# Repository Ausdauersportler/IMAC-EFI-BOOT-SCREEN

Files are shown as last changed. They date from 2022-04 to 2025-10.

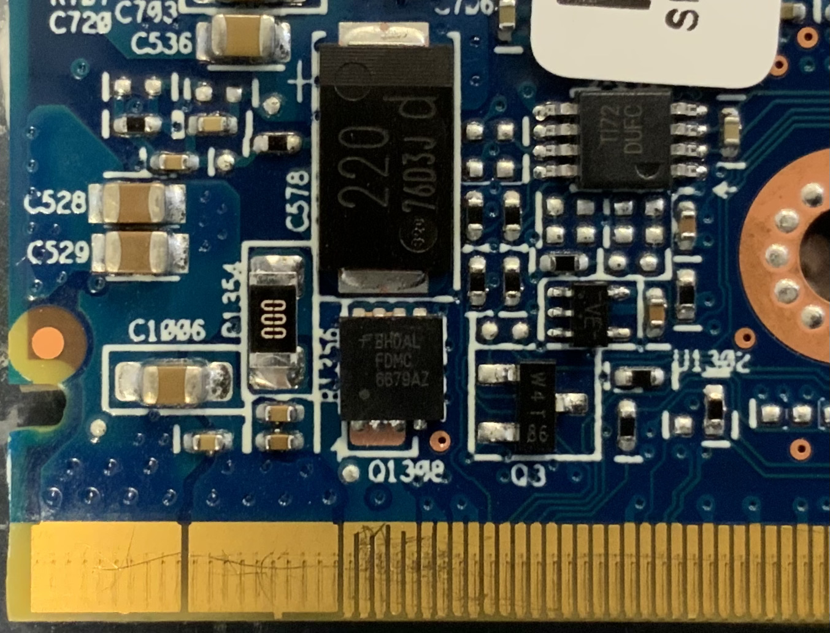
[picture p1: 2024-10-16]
images/modded_corner.jpg

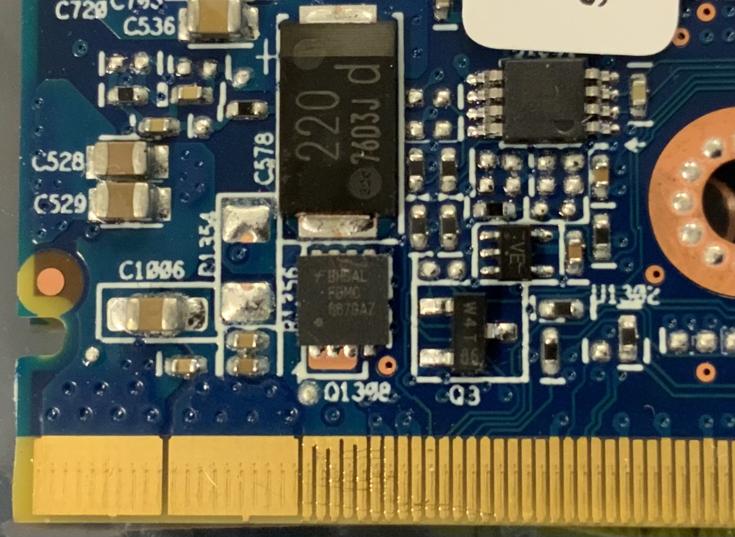
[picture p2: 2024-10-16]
images/unmodded_corner.jpg

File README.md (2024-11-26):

# IMAC-EFI-BOOT-SCREEN

How to create an EFI boot screen vBIOS for Apple 2009 to Mid 2011 iMac systems using AMD MXM3 graphics cards

My goal is to provide a comprehensive guide how to construct EFI BIOS versions for some AMD MXM cards. As described in detail in this [thread](https://forums.macrumors.com/threads/2011-imac-graphics-card-upgrade.1596614/post-17425857) owners of modular Apple iMac models built in 2009-2011 with MXM slot graphcs card can replace the original ATI card either with an Nvidia Kepler or an AMD GCN 1.0 to 4.0 card. While there has been a lot of success offering an EFI boot screen with NVIDIA cards development stuck with the AMD cards at some point where an iMac firmware modification has been proposed. Although the firmware modification is quite simple the adoption rate is frankly speaking zero. IMHO this is still the best way to go. Nevertheless even this method will need a BIOS constructed in the same way as described here within the wiki. 

Just to complete this introduction: 
Lately [improvements](https://forums.macrumors.com/threads/imac-2011-maxwell-and-pascal-gpu-upgrade.2300989/post-30017630) have been made to add a NVIDIA Maxwell and Pascal card, but please note there are no macOS drivers available within any macOS versions starting with Mojave, and there is limited EFI boot screen support.

The [wiki](https://github.com/Ausdauersportler/IMAC-EFI-BOOT-SCREEN/wiki) decribes tools, sources, methods, orignal limitations, solutions and state of the current development.  

## iMac models supported

This repository is limited to these eight iMac models published from 2009 to 2011:

- iMac9,1 Early 2009 A1225 24 inch (LVDS) (using a modified EnableGop9,1 driver, see note 1)
- iMac10,1 Late 2009 A1311 21.5 inch (LVDS) (see note 2)

- iMac10,1 Late 2009 A1312 27 inch (eDP, see note 3 about EG2)

- iMac11,1 Late 2009 A1312 27 inch (eDP)
- iMac11,2 Mid 2010 A1311 21.5 inch (eDP)
- iMac11,3 Mid 2010 A1312 27 inch (eDP)

- iMac12,1 Mid 2011 A1311 21.5 inch (eDP)
- iMac12,2 Mid 2011 A1312 27 inch (eDP)

Notes: 

1. Finally it was possible to include the iMac9,1 Mid 2009 A1225 24 inch to this list. The [2.93 GHz](https://everymac.com/systems/apple/imac/specs/imac-core-2-duo-3.06-24-inch-aluminum-early-2009-specs.html) and [3.06 GHz](https://everymac.com/systems/apple/imac/specs/imac-core-2-duo-2.93-24-inch-aluminum-early-2009-specs.html) versions were equipped with MXM3 slots and non metal graphics cards (GT120, GT130, AMD 4850). Best cards to use are the AMD FirePro M4000, M5100, W5170M, and M6000. The power hungry Saturn cards M6100 and W6170M/W6150M will over heat the system under load rapidly. This system needs a special EnableGop91 driver. All vBIOS files are marked aka named like this and include the LVDS string, too. Some more recent NVIDIA MXM3 cards may still have LVDS signaling support and therfore may work with these iMac9,1 system, too (never tested).

2. vBIOS file names contain the string LVDS, but not show the EnableGop91 string (see note 1). Unfortunately all more recent AMD GPUS starting the the Polaris/GCN4 architecture lack LVDS signaling hardware support. Therefore you cannot get those cards to display the boot screen unless you connect the internal display using a third party display driver board the external DP port - making it an externally connected display.

3. EG2 versions of vBIOS do not run on iMac10,1 A1312 systems, you get only a white screen in power on/boot. EG versions support all types of Macs listed.

4. Althout one cannot modify the legacy part of the vBIOS it is possible to inject a modified legacy vBIOS (the first 64K of it) using an SSDT or OpenCore DeviceProperties (ATY,bin_image) to enable the backlight control on Big Sur and Monterey. This mod does not apply or work with any Windows installation. Adding the EnableGop driver brought back EFI boot screen support. First and only replacement card which enables both external display connectors on iMac12,2.

5. Same method as described above enables virtual brightness control on RX6600M. Although values in ioreg and NVRAM are changed the brightness of the display itself does not change, probably because MXM PINS 23,25,27 are not connected as described in this [video](https://www.bilibili.com/video/BV1Ec411d7z6). Additionally the GOP driver has to be patched with the [Syncretic tool](https://forums.macrumors.com/threads/amd-radeon-rx-6800-xt-6900-xt-for-macos.2262295/page-36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). Unfortunately neither EnableGop not OpenCore are able to switch on the internal backlight, so the display comes to life late at the login screen. 

## AMD graphcis cards supported

Currently we have tested these cards and can confirm the method works with:

- AMD FirePro M4000
- AMD FirePro M5100
- AMD FirePro M6000
- AMD FirePro W5170M

- AMD FirePro M6100
- AMD FirePro W6150M
- AMD FirePro W6170M

- AMD FirePro W7170M 
- AMD FirePro S7100X

- AMD Radeon Pro WX4130 mobile
- AMD Radeon Pro WX4150 mobile
- AMD Radeon Pro WX4170 mobile

- AMD Radeon Pro WX3200 mobile

- AMD Radeon Pro RX470 mobile
- AMD Radeon Pro RX480 mobile
- AMD Radeon Pro WX7100 mobile

- AMD Radeon Pro RX5500XT mobile (see note 4 above)
- AMD Radeon Pro RX6600M mobile (see note 5 above)

## Hardware upgrade (wiki)

You will find an [overwiew](https://github.com/Ausdauersportler/IMAC-EFI-BOOT-SCREEN/wiki/WWWW) which card works in which iMac and how to start the upgrade project and some more hardware related information about minor soldering tasks needed for a few cards to make them fully compatible in a newly added hardware section.

## Credits

Most knowledge has been gathered by me from contributions made by [Nick [D]vB](https://github.com/iMacGFX), [nikey22](https://github.com/nikey22), and [internetzel](https://github.com/internetzel) who spent some nights to explain everything in detail to me and who has much more patience to dive deeply into this matter than I do. Hope he will join me to fill this repository with contents. Last but not least thanks to [dfranetic](https://github.com/franetic), he finished what I could not have done. Great team!

Thanks to [rthpjm](https://forums.macrumors.com/members/rthpjm.535915/) for finding a W6150M and the necessary legacy vBIOS in some HP firmware update. Special thanks to [edwardgeo](https://forums.macrumors.com/members/edwardgeo.1274066/) for countless ideas and incredible knowledge about indepth AMD vBIOS modifications. All the best if these dark times!

[m0bil](https://github.com/m0bil) has become the expert for all NVIDIA modifications and probably he should start a similar repository about it and more importantly to this project he is the undisputed master of all iMac firmware modifications.

Finally many thanks to [Mike Beaton](https://github.com/mikebeaton) who developed an EFI driver named [EnableGop](https://github.com/mikebeaton/OpenCorePkg/tree/master/Staging/EnableGop) usable for both MacPro5,1 and modular iMacs as listed above using either Nvidia or AMD graphics cards to enable the EFI boot picker. I had to modify this driver a little bit to make it work on the older (LVDS) iMac9,1 model. This change has not been included into the EnableGop source tree and you need to get the driver named EnableGop91 compiled from this page. It works as desigend, with AMD and likely with NVIDIA cards as well.

## Support

If you want to support the AMD (i)Mac vBIOS development or just buy me a coffee [donations](https://www.paypal.com/paypalme/Ausdauersportler) are greatly appreciated.

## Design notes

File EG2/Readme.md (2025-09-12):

EFI compatible vBIOS versions based on Apples own EG2 driver (extracted from different MacBookPro and iMac firmware).
Most native experience when using these EG2 versions, no glitches and no display sync problems. 
Needs an iMac firmware modification as described in the wiki. 
An alternative solution is deleting the VGA driver from the legacy part to gain some space needed to add both the CoreEG2 and EDIDParser modules.

Optimal choice for macOS only systems.

UEFI Windows support only with AMD GOP injection via OCLP.

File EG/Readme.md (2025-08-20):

All vBIOS versions uploaded here are created to use in Apple iMac models, only. No support for any PC laptops here.

Tried to use speaking file names to avoid confusion after downloading multiple files from this and other folders in this repository.
Files containing the EnableGop string use the OpenCore EnableGop driver and will enable backlight on power on and show the EFI boot picker when pressing alt/option on all listed iMac models!

The iMac9.1 limited by an older and different firmware version needed a modified version of the EnableGop driver. I managed to get it working and now we support all ever manufactured Mac desktop systesm with MXM3 slots. The vBIOS versions are labeled as with EnableGop91 as part of the file name. 

Files containing the LVDS string are meant for both LVDS systems: iMac9,1 24" and iMac10,1 21.5" 
All other files are optimized for eDP connected internal displays as found in the iMac10,1 27 inch, all iMac11,x and iMac12,x models.

Some files contain names like Elpida, Samsung, and Hynix (VRAM manufacturing companies). 
Hynix memory comes on two different flavors, AFR and BFR.
It will help you to identify the correct version in case you see multiple similar named vBIOS files.
Some files just contain an ALT name tag (same as above, but it is just an alternative VRAM support version without naming special vendors).
If the normal version causes problems try the ALT version. 

All file names begin with the graphics card marketing name chosen by the vendor, i.e. WX4130 (AMD Radeon Pro WX 4130).

Since not all GPU chips are really identical (binning ) some cards may run with higher VRAM or core clock speed settings. The WX4170 versions are forcing such higher clock speeds. If you experience any form of instability use the slightly lower clocked WX4150 versions, instead. One cannot change the GPU chip characteristics after production.

We usually did not change power, voltage or clock settings to avoid any stability issues. 
But we cannot guarantee you got a card running well with vBIOS versions provided here.

The recent version of the EnableGop driver is V1.4 - I may update all vBIOS files in future, but I will only provide such updates if serious issues will be fixed. So far - as iMacs are concerned - no such issues are known. Each card works well even with the first public 1.1 release.

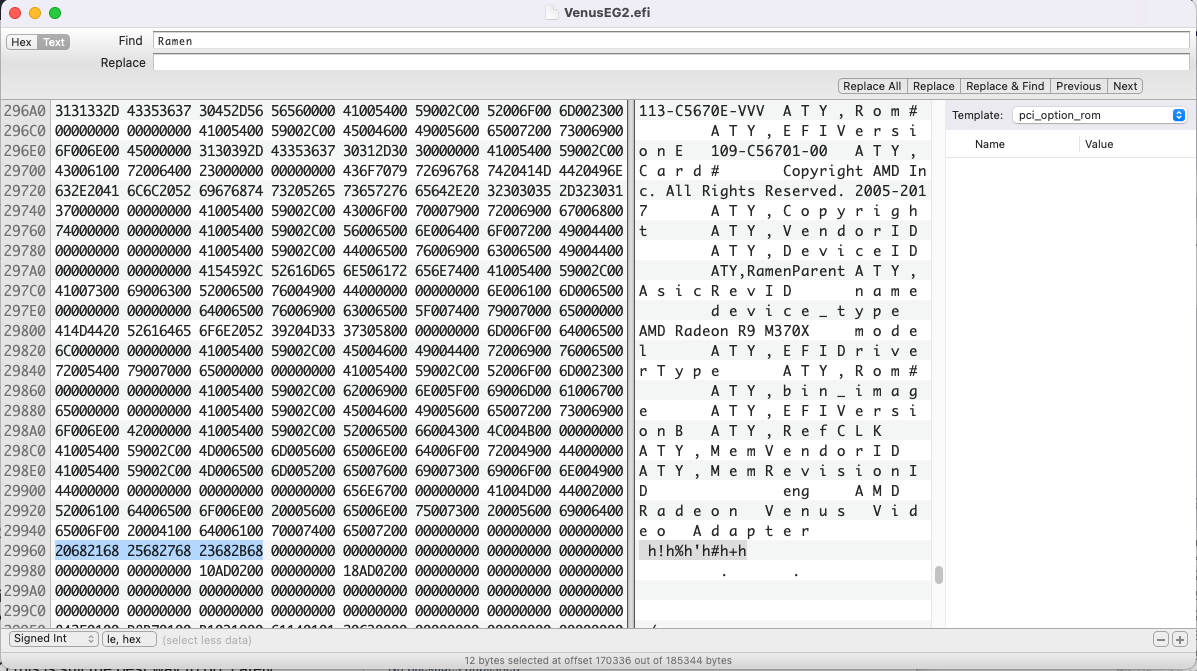
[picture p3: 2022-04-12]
images/Ramen.png

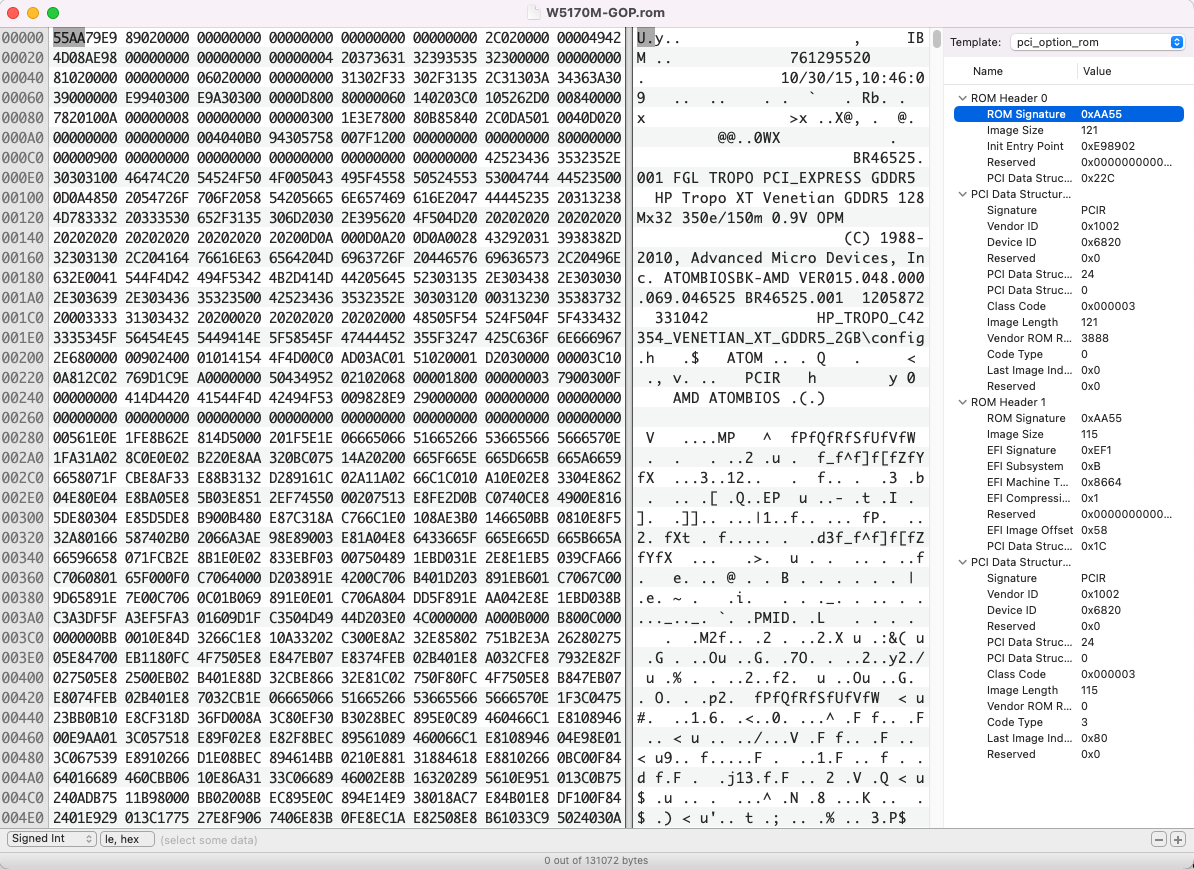
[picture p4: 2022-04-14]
images/PC_OPTION_ROM.png

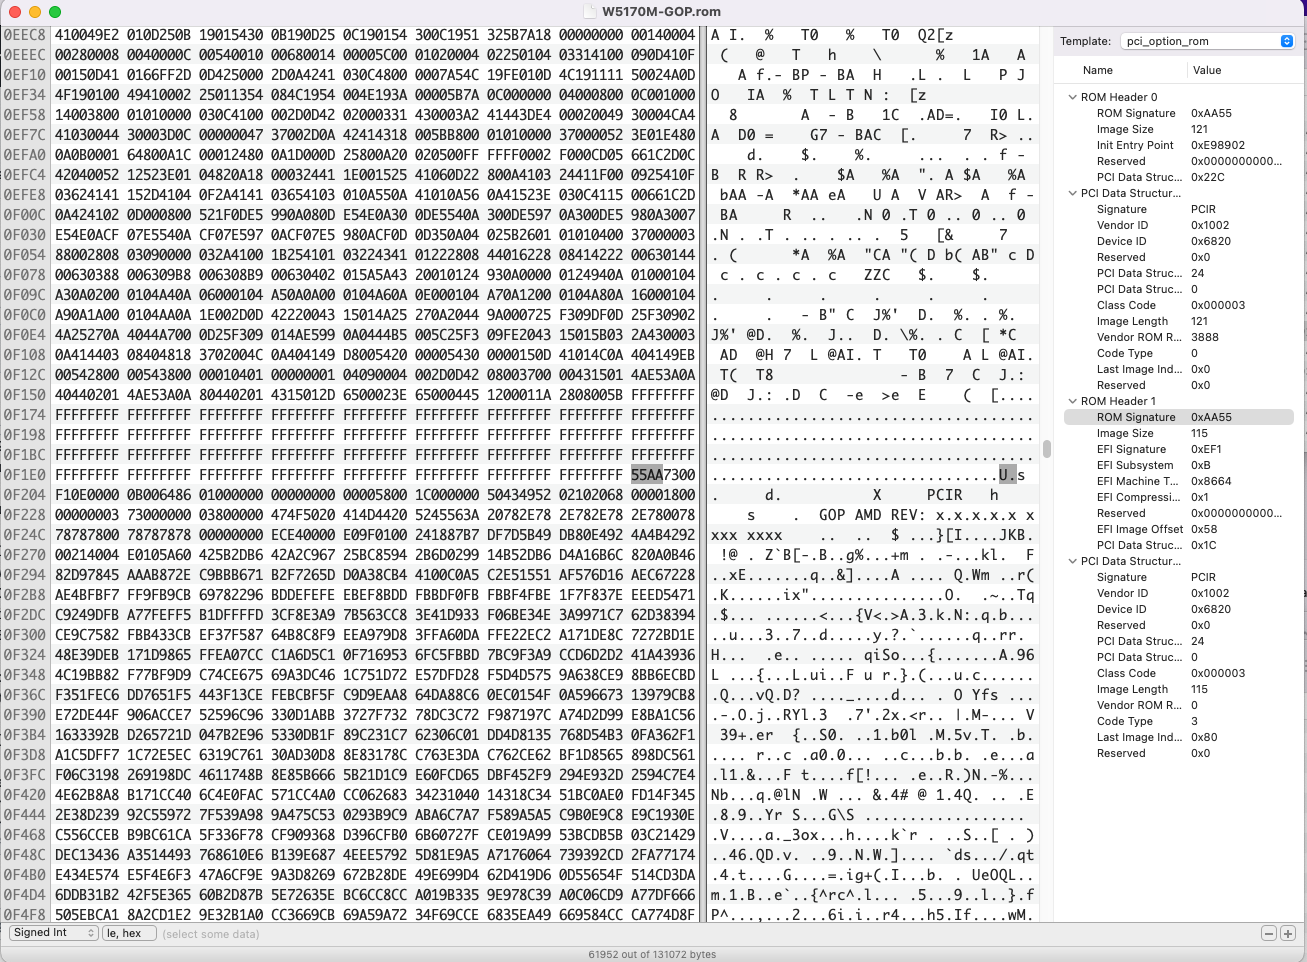
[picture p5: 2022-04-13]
images/OverwriteGOPWithEG2.png

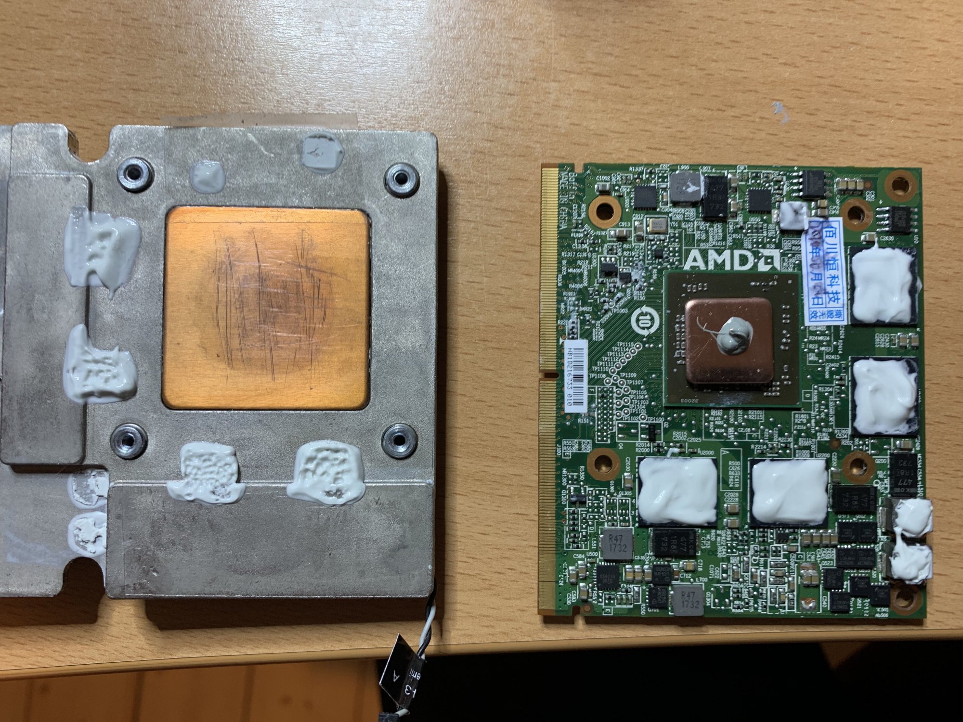
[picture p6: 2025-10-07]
images/WX4130+1mmCopper.jpg

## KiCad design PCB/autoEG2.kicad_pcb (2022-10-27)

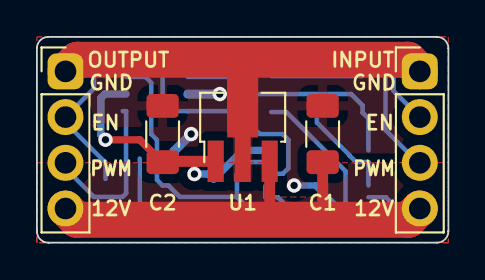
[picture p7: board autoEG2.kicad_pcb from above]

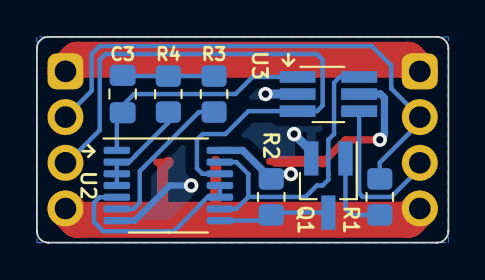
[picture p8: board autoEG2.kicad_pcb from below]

Board: 2 copper layers, 22.9 x 11.4 mm, 13 parts (8 on the bottom side), 14 nets.

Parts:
C1, C2: 1u; C_1206_3216Metric_Pad1.33x1.80mm_HandSolder
C3: 1nF; C_0805_2012Metric_Pad1.18x1.45mm_HandSolder
INPUT: Conn_01x04_Male; PinHeader_1x04_P2.54mm_Vertical
OUTPUT: Conn_01x04_Male; PinHeader_1x04_P2.54mm_Vertical
Q1: MMBT3904; SOT-23_Handsoldering
R1: 47k; R_0805_2012Metric_Pad1.20x1.40mm_HandSolder
R2: 22k; R_0805_2012Metric_Pad1.20x1.40mm_HandSolder
R3: 330k; R_0805_2012Metric_Pad1.20x1.40mm_HandSolder
R4: 33k; R_0805_2012Metric_Pad1.20x1.40mm_HandSolder
U1: L78L33; SOT-89-3_Handsoldering
U2: 74HC02; TSSOP-14_4.4x5mm_P0.65mm
U3: 74LVC1G157; TSOT-23-6_HandSoldering

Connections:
+12V: C1.1, INPUT.4, OUTPUT.4, U1.3 (IN)
/Q: U2.5, U2.10, U2.11
/R: Q1.3 (C), R2.2, U2.8
/S: INPUT.3, U2.12, U3.3 (I0)
/~Q: U2.9, U2.13, U3.6 (S)
GND: C1.2, C2.2, INPUT.1, OUTPUT.1, Q1.2 (E), U1.2 (GND), U2.7 (GND), U3.2 (GND)
unnamed: C3.1, U2.1, U3.1 (I1)
unnamed: C3.2, R3.2, R4.2
unnamed: Q1.1 (B), R1.2
unnamed: INPUT.2, OUTPUT.2, R1.1
unnamed: R3.1, U2.6
unnamed: R4.1, U2.2, U2.3, U2.4
unnamed: OUTPUT.3, U3.4 (Y)
VCC: C2.1, R2.1, U1.1 (OUT), U2.14 (VCC), U3.5 (VCC)

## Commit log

2022-04-12 Hex Fiend
    Searching the frame buffer name and supported device-id
2022-04-13 Add files via upload
    EFirom compressed version of M370.efi with device-id 0x6820.
2022-04-13 Add files via upload
    EFIrom macOS executable (terminal, in case you cannot start it adjust permissions using chmod)
2022-04-14 Add files via upload
    Amethyst and Saturn wire-mod to enable the internal backlight on boot. Using a switch to select this constant 3V feed and the modulated PWM signal during normal use (normal wiring) makes it an option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
2022-08-24 Add files via upload
    Table of default values for some connector variables Mac M370 GPU
2022-10-27 Add files via upload
    AMD GOP driver used in all GOP vBIOS versions to be used with OpenCore in UEFI/Drivers section
2022-10-27 add-on PCB KiCad design files
    [autoEG2.kicad_pcb, autoEG2.kicad_sch]
2022-11-01 add-on PCB schematic
2022-11-02 add-on PCB cable connections
2022-11-25 RX5500XT MXM
    This is already an GOP vBIOS. Since we cannot modify the legacy part and cannot fix the OBJ_INFO module to adapt one connector to eDP I will not upload a fixed GOP vBIOS. Please to not flash on different card, you man need a hardware flash tool to recover if booting fails.
2022-11-25 RX5500XT
    RX5500XT Navi 14 compatible EG2 driver pulled from MP7,1 firmware
    Convert with `EfiRom -ec NV14Python_EG2.efi -l 0x30000 -f 0x1002 -i 0x7340 -p -o NV14Python_EG2_.rom` into EG2 rom and exchange with existing GOP. Needs iMac EG2 modded firmware to provide an EFI Boo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
2022-11-29 UEFI Windows support
    You need BootCamp drivers installed and the driver signature patch applied to avoid error 43.
    Alternatively you can always try to install legacy Windows via DVD since the EFI picker is working now (not tested).
2022-11-29 UEFI Windows 10
    added @nikey22 head patch to enable AMD drivers to recognize the card properly
2023-03-05 Add files via upload
    New OBJ_Info module no longer needing OpenCore connectors and connector-count entries.
2023-03-17 experimental and not tested
    - please be ready to clip flash in case of trouble
2023-04-20 WX7100 (not tested)
    This the the EG version of the WX7100-GOP.rom published in the GOP folder. If you currently use the GOP version chances are good with new vBIOS might enable the EFI Boot screen for you, too.
2023-05-11 iMac9,1 EFI boot screen version
    Please use until further notice only on iMac9,1 24" models with MXM3 slot!
2023-05-13 iMac9,1 EFI support
    Note about adding iMac9,1 EFI boot screen support using a modified EnableGop driver.
2023-10-15 Added VRAM support
    This M6100 version contains another VRAM module apparently supporting all types of Hynix, Samsung, and Elpida memory. EFI boot screen support with EnableGop driver included.
2023-10-15 M6100 simplified VRAM support
    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
2023-10-15 Update EG driver support information
2023-11-24 2nd alternative VRAM support
    WX4150 and WX4170 version with Hynix AJR memory - in case neither the normal or ALT version work properly give this a try. As usual an EnableGop version offers EFI Boot picker support.
2025-03-12 AMD RX480 EG
    EnableGop driver, 67W for cooler run time behavior, Windows UEFI support
2025-08-20 Update Readme.md
    Minor clarification about EnableGop driver versions. All cards will work using the first public release 1.1.
2025-08-20 4GB VRAM version
    The first RX5500XT-EnableGop file supports 8GB VRAM, only. The new version (speaking names) supports 4GB VRAM. The EnableGop driver version 1.4 has been used. Both cards need the PCB @franetic developed to enable the LCD backlight on boot/reboot to show the EFI picker. Otherwise you will need to pick the boot disk blindly.
